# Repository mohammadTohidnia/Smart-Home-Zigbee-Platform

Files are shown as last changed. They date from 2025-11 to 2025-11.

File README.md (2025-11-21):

# Smart-Home-Zigbee-Platform 

**A comprehensive, cost-effective, and scalable solution for residential automation using the Zigbee protocol.**

## Project Overview
This project addresses common challenges in smart home development, such as power consumption, network coverage, and device integration. We have designed a complete system based on the Zigbee protocol that includes custom hardware and software integration.

Key capabilities include:
* **Universal Compatibility:** Capable of adding any Zigbee device from any brand to the network.
* **Automatic Device Discovery:** Seamless integration of new nodes.
* **Real-time Control:** Instant feedback and command execution via a remote platform.
* **Extended Network Coverage:** Robust signal stability using custom router nodes.
* **High Scalability:** Designed to support a large number of devices in a mesh network.

## System Architecture
The platform consists of three main components:

1.  **Zigbee Hub (Central Node)** 
    * **Hardware:** A **custom-designed PCB** hosting an **Orange Pi Zero 3**. It integrates the Zigbee module and power management to act as the network coordinator.
    * **Software:** Runs **Zigbee2MQTT** to bridge Zigbee traffic to the MQTT protocol, transmitting data to **ThingsBoard** for monitoring and control.

2.  **Zigbee Router (Repeater)** 
    * **Function:** Enhances network coverage and signal stability by relaying messages between End Devices and the Hub.
    * **Design:** A standalone custom PCB powered by a 5V adapter.

3.  **In-Wall Switch (End Device)** 
    * **Function:** Smart lighting control with manual override capabilities.
    * **Design:** A compact custom PCB designed to fit into standard wall switch boxes, controlling high-voltage loads via a relay.

---

# 1. Zigbee Hub (Central Node) 

The Hub acts as the brain of the system, hosting the MQTT broker and bridging Zigbee communication to the ThingsBoard platform.

## Hardware
* **Core:** [Orange Pi Zero 3](http://www.orangepi.org/).
* **Carrier Board:** Custom-designed PCB acting as the main hub.
* **Zigbee Module:** **RF-BM-2652P4I** (based on TI CC2652P7), integrated directly onto the custom PCB.

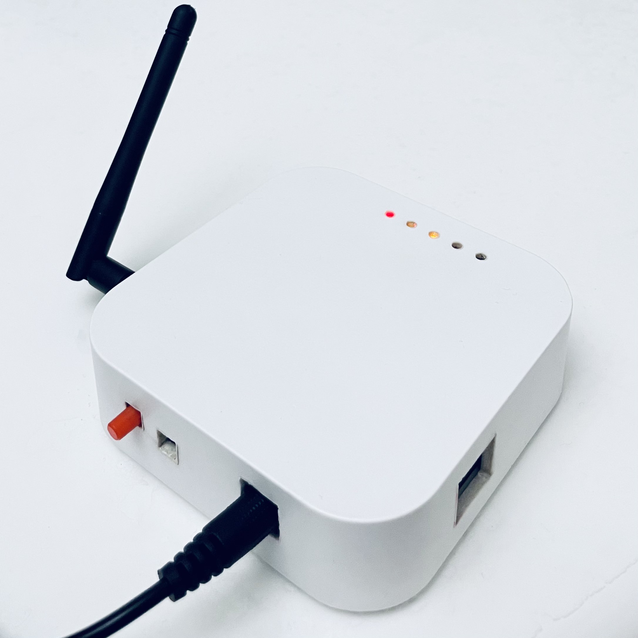
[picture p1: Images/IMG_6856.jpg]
ZigBee Hub


## Software Setup

### 1. Orange Pi Setup (OS & Connectivity)
We used the **Orange Pi Zero 3** as the computational platform.

* **OS Installation:**
    1.  Download the **Debian Bookworm** image from the [Orange Pi Website](http://www.orangepi.org/html/serviceAndSupport/index.html).
    2.  Download and install [Balena Etcher](https://balena.io/etcher).
    3.  Flash the image onto a microSD card (min 8GB).
* **Initial Connection (UART):**
    * Connect a **USB-TTL converter** to the Orange Pi (TX to RX, RX to TX).
    * Open a serial terminal (e.g., [MobaXterm](https://mobaxterm.mobatek.net/)) at **115200 baud** to access the console.
* **Network & SSH:**
    * Connect to Wi-Fi:
        ```bash
        sudo nmtui
        ```
    * Get the IP address:
        ```bash
        ip a
        ```
    * Connect via SSH for easier management:
        ```bash
        ssh orangepi@<YOUR_IP_ADDRESS>
        ```

### 2. Installing Dependencies & Broker
To bridge Zigbee devices with the MQTT protocol, we need Node.js and an MQTT broker.

1.  **Install Basic Tools & Mosquitto Broker:**
    ```bash
    sudo apt update
    sudo apt install -y mosquitto mosquitto-clients git make g++ gcc
    ```
2.  **Install Node.js (Required for Z2M):**
    ```bash
    curl -fsSL [https://deb.nodesource.com/setup_20.x](https://deb.nodesource.com/setup_20.x) | sudo -E bash -
    sudo apt install -y nodejs
    ```
3.  **Verify Installation:**
    ```bash
    node -v
    npm -v
    ```

### 3. Installing Zigbee2MQTT
We followed the official [Linux Installation Guide](https://www.zigbee2mqtt.io/guide/installation/01_linux.html).

1.  **Clone the Repository:**
    ```bash
    sudo git clone [https://github.com/Koenkk/zigbee2mqtt.git](https://github.com/Koenkk/zigbee2mqtt.git) /opt/zigbee2mqtt
    sudo chown -R $USER:$USER /opt/zigbee2mqtt
    ```
2.  **Install Dependencies:**
    ```bash
    cd /opt/zigbee2mqtt
    npm ci
    ```

### 4. Configuration
Edit the configuration file to target the custom PCB's serial port and the local broker.

1.  **Open Configuration:**
    ```bash
    nano /opt/zigbee2mqtt/data/configuration.yaml
    ```
2.  **Paste Configuration:**
    ```yaml
    # MQTT Settings
    mqtt:
      base_topic: zigbee2mqtt
      server: 'mqtt://localhost'

    # Serial Settings (Custom PCB)
    serial:
      port: /dev/ttyS5       # UART5 connected to CC2652P7
      baudrate: 115200
      adapter: zstack

    # Frontend (Web Interface)
    frontend:
      enabled: true
      port: 8080
    ```
3.  **Start Zigbee2MQTT:**
    ```bash
    npm start
    ```

### 5. Flashing the Firmware (CC2652P7)
The **RF-BM-2652P4I** chip on the PCB requires the Z-Stack Coordinator firmware.

* **Firmware:** Use this [link](https://github.com/JelmerT/cc2538-bsl) to access the required firmware based on your hardware.
* **Tool:** [cc2538-bsl](https://github.com/JelmerT/cc2538-bsl).
* **Steps:**
    1.  Hold the **BOOT** button on the PCB and press **RESET** to enter bootloader mode.
    2.  Run the flashing command:
        ```bash
        python3 cc2538-bsl.py -p /dev/ttyS5 -evw coordinator_firmware.hex
        ```

### 6. ThingsBoard Integration (Cloud Bridge) 
To enable remote monitoring and control, we developed a custom Python script that acts as a bridge between the local MQTT broker (Mosquitto) and the ThingsBoard Cloud platform.

#### Features
* **Telemetry Upload:** Pushes `Linkquality` and `LED` status from Zigbee2MQTT to ThingsBoard.
* **Remote Control (RPC):** Listens for `setLED` commands from ThingsBoard to toggle the In-Wall Switch.

#### Setup
1.  **Install Python Dependencies:**
    The script requires the Paho MQTT client.
    ```bash
    sudo apt install python3-pip
    pip3 install paho-mqtt
    ```

2.  **Configuration:**
    Open the python script (`/Software/codes/zig_to_tb/zig_to_tb3.py`) and update the **ThingsBoard settings**:
    ```python
    THINGSBOARD_HOST = 'tb2.thingsware.cloud'
    ACCESS_TOKEN = 'YOUR_ACCESS_TOKEN' # Replace with your actual ThingsBoard Device Token
    ```

3.  **Running the Bridge:**
    You can run the script manually for testing:
    ```bash
    python3 zig_to_tb3.py
    ```

---

# 2. Zigbee Router (Repeater) 

The Zigbee Router is a standalone node designed to extend the range and stability of the network. It operates solely using the Zigbee module and does not require a computational board.

## Hardware
* **Zigbee Module:** **RF-BM-2652P4I** (TI CC2652P7).
    * Selected for its high output power (20 dBm) to maximize range.
* **Power Supply:** 5V 1A adapter with an **AMS1117-3.3** regulator.
* **Antenna:** External antenna via IPEX connector.
* **Enclosure:** Custom casing.

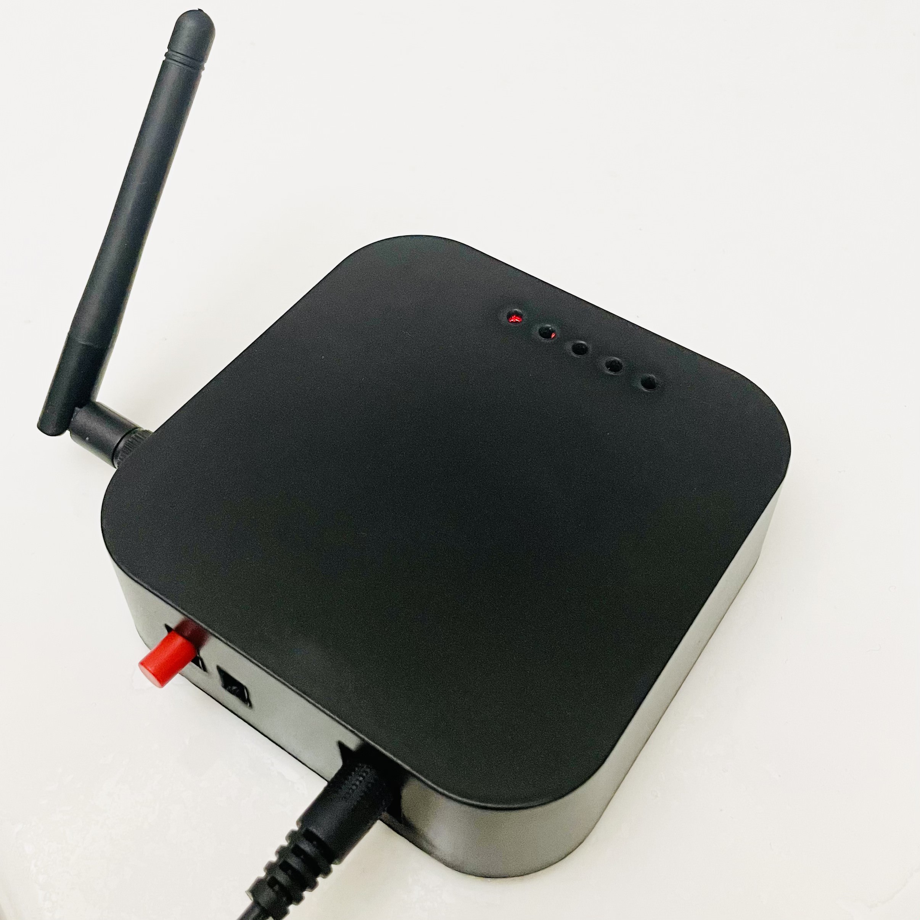
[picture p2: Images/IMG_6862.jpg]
ZigBee Router


## Functionality
* **Signal Repeater:** Relays data between End Devices and the Hub.
* **Mesh Networking:** Healing and routing for network stability.

## Firmware Setup
To configure and flash the router, we use the **PTVO** tool to generate a custom firmware image, followed by `cc2538-bsl` to upload it.

### Step 1: Generate Firmware
1.  Download and install **[Zigbee Configurable Firmware (PTVO)](https://ptvo.info/)**.
2.  Open the tool and select **CC2652P7** as the target chip.
3.  Configure the device role as **Router**.
4.  (Optional) Map any status LEDs or diagnostic pins used on the custom PCB.
5.  Save/Generate the firmware file (e.g., `router_firmware.hex`).

### Step 2: Flash Firmware
1.  **Connect:** Attach the Router PCB to your PC using a **USB-TTL converter**.
2.  **Enter Boot Mode:** Hold the **BOOT** button on the PCB, press **RESET**, then release BOOT.
3.  **Flash:**
    ```bash
    python3 cc2538-bsl.py -p <YOUR_PC_COM_PORT> -evw router_firmware.hex
    ```

---

# 3. Zigbee In-Wall Switch (End Device) 

The In-Wall Switch is a smart end device capable of controlling AC loads (lights/appliances). It supports both wireless control via Zigbee and manual control via a physical button.

## Hardware
* **Chip:** **ESP32-C6** (Supports Zigbee 3.0, Wi-Fi 6, BLE 5.0).
* **Power:** **WX-DC12003** AC-DC converter (Mains to 5V) + **AMS1117-3.3**.
* **Relay:** **HF49FD** (5A, 250V AC) for load switching.
* **Safety:** Includes a slow-blow fuse (0697H1000-02) for overcurrent protection.

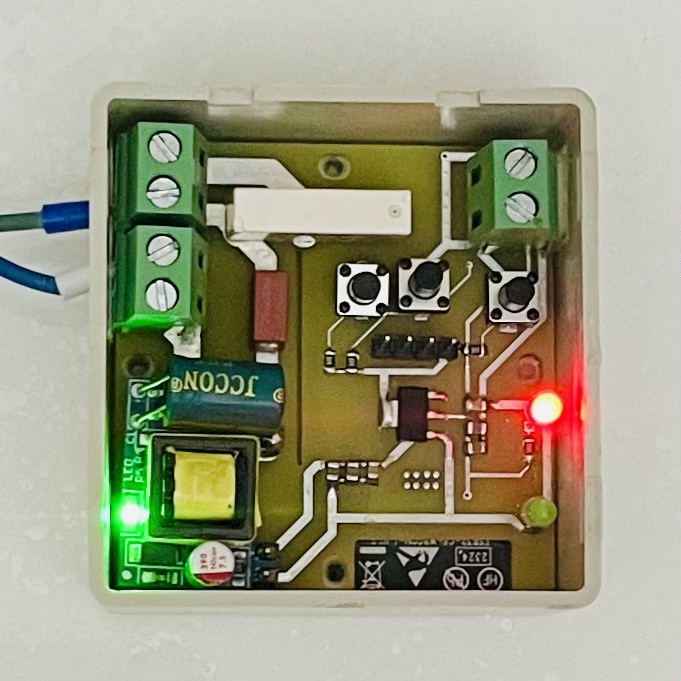
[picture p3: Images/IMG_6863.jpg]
ZigBee In-Wall Switch1

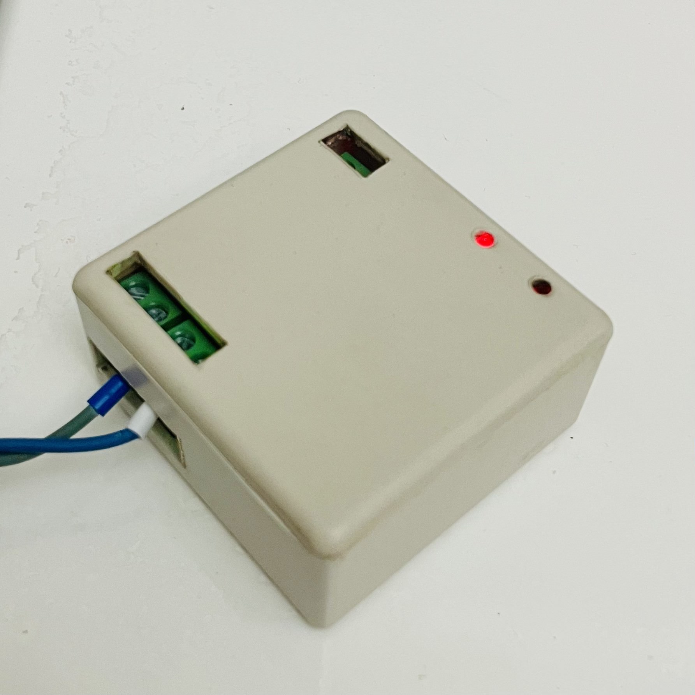
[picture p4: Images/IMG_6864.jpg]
ZigBee In-Wall Switch2


## Firmware Logic (C++)
The firmware was developed using the **Arduino IDE** and the **ESP32 Zigbee SDK**. The source code is located in the `/In-Wall-Switch/Firmware` directory.

### Key Features:
1.  **Zigbee End Device:** Acts as an endpoint in the network.
2.  **Pairing Mode:** Holding the physical button for **>5 seconds** triggers factory reset and enters pairing mode (LED flashes fast).
3.  **Manual Override:** Pressing the button toggles the relay and immediately reports the new state to the Hub.
4.  **Connectivity Reporting:** Sends signal strength (`linkquality`) and state (`ON/OFF`) to the Hub.

### Flashing Instructions:
You can flash the firmware using the **Arduino IDE** or the command line tools.

1.  **Connect:** Attach the Switch PCB to your PC via USB-TTL (connected to the ESP32-C6 UART pins).
2.  **Enter Boot Mode:** Put the ESP32-C6 into bootloader mode (Hold BOOT, press RESET).
3.  **Flash via Arduino IDE:**
    * Select Board: `ESP32C6 Dev Module`.
    * Select Port: Your COM port.
    * Click **Upload**.
4.  **Flash via Command Line (esptool):**
    ```bash
    esptool.py --chip esp32c6 --port <YOUR_PORT> --baud 115200 write_flash 0x0 switch_firmware.bin
    ```

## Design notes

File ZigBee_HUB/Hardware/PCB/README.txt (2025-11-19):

This is the final version of Zigbee HUB with Orange PI. The features:
1. It is designed in a way that can be used as HUB or Router. If you use HUB, Do not assemble Regulator components. 
If you want Router, you have to assemble the AMS1117 regulator.

2. It has some pin headers for future developments (I2C and SPI of CC2652P4I)

3. It needs a 5V/2A or 5V/3A adaptor to power the board.

4. If you see a voltage drop, you can short circuit the schottky diode.

5. In new version, the LEDs are smd and they need a LENZ to make the light better and straight.

6. If you hold the reset button for more than 3 secs, you put the hub into pairing mode and it allows devices to join the network.

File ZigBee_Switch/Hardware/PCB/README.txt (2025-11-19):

The final version is a zigbee InWall switch with one relay that connects to the Zigbee HUB. The proble is the dimensions of the PCB. 
We have to design a new PCB with other Power Supply that can convert 220 VAC to 5V DC in a small space. My solution is to use LNK306
switching regulator that offers a good output current for this circuit. The schematic is in this LInK : https://www.instructables.com/LNK304-Transformerless-Power-Supply/
The goal is to design a PCb less than 50 mm in dimensions.

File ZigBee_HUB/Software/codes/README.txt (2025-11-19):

File "Connection Status" -> A python code for GPIO pins of Orange pi to control the led indicators for connection status.
This file is the final version and the code works fine.

File "Zig_to_tb" -> A python code to connect the zigbee network to thingsboard. You need the Access token of your device in this code.
The code works fine, but it is needed to get better. For example, we have to write a code that creates the hub as a device in thingsboard
automatically. In this way, there is no need to define access token for each device. For now, "zig_to_tb3" is better version that can
connect to thingsboard.

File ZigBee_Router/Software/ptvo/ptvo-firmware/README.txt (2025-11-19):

This firmware allows you to create a device with a flexible configuration of inputs and outputs.

The device with this firmware also works as a router.

How to use
=========================

1. Launch the "FirmwareConfig.exe" utility.
2. Configure the firmware for your chip, board, and needs. Optionally, you may click the "File - Read settings from a file" menu item and load settings from an existing preset in the "Presets" folder.
3. Click the "Save" button and get the final HEX file. Note: some features may require the Premium version of this firmware.

Options
=========================

Remember state - The firmware saves the output state to NVRAM and restores it after power off/on.

Link - The input immediately controls the state of the corresponding output. The device sends the on/off state of
the output to a coordinator. Otherwise, the input is independent.

Long - The firmware detects and reports to the coordinator a long click (2000 ms)

Double - The firmware detects and reports double click (max 500 ms between clicks)

Tripple - The firmware detects and reports tripple click (max 500 ms between clicks)

Switch - an input works as a switch. Only ON (pushed) / OFF (released) states.

UART
=========================

The UART interface is designed to send text commands between an external device (e.g. Arduino) and a host. 

The maximum command size is 127 characters. Every command line should ends with CR (0x0D). If you need 
to send a number to a host, you should convert it to text.

UART uses P02 and P03 pins (3.3V). You should enable UART on one of output pins in the configuration.

UART parameters: 9600 8N1. You cannot change these parameters.

External sensors 
=========================

The firmware supports up to 8 external sensors of different types. 
Keep in mind, that CC253x has limited performance. You cannot attach 8 sensors, 4 inputs, UART and get a good result.
Some sensors cannot co-exist with each other.

I2C sensors (BMx280, SI7021, etc)
---
You should define a pin for a sensor first. It is the SDA pin. Then you should define the SCL pin. 
For example, output 7 - BME280, and output 8 - I2C SCL

DS18B20
---
The firmware supports up to 4 sensors on one line. But all values will be sent to one endpoint with a different description.

Pulse generator
---
You may use this generator to wake-up Atmega based sensor. That should measure a value and output it to an UART port.

Pulse counter
---
It is 32 bit counter with the 10 milliseconds debounce interval. Therefore it cannot be used for high frequence signals.
If an interval is defined, the counter automatically resets after that interval and reports the counted values to a coordinator.

MHZ19, Senseair
---
These sensors should work in the UART mode and connected to UART pins. Therefore you cannot use the UART interface in the same
configuration. (CC2530 P0.2 -> MH-Z19 RX, CC2530 P0.3 -> MH-Z19 TX)

Bistable relay
==========================

You should define ON pin first. For example, output 7 - Bistable relay ON, and output 8 - Bistable relay OFF

Analog inputs
==========================

You may define up to 8 analog inputs in the configuration. You can connect analog inputs to pins P00..P07.

Analog input, accurate (max 1.15V) - the pin uses internal reference voltage that is more precise than an source voltage.
Analog input, (max 3.3V) - less accurate, but it can measure higher voltage.
Source voltage - reports source power voltage. It can be used to monitor a battery level.
Internal temperature - reports a temperature of the CC2530 chips.

The firmware reads analog values when it sends a periodic report to a host. When the periodic report is disabled you should
send the "read" request for the configured endpoint.

Experts options
==========================

You should know what you change.

Zigbee internals
=========================

1. The firmware creates a separate endpoint (1..8) for every configured output and/or input (max 8 endpoints).

2. The firmware reports the state of an independent button via the "ZCL_CLUSTER_ID_GEN_MULTISTATE_INPUT_BASIC" cluster 
   and the "PRESENT_VALUE" attribute.

   1 - single click.
   2 - double click.
   3 - tripple click.
   4 - long click.

4. The firmware does not send a separate report for the linked button. Otherwise, it sends reports about the output state 
  via the "ZCL_CLUSTER_ID_GEN_ON_OFF" cluster and the "ON_OFF" attribute.
  
5. You may control the output state via the "ZCL_CLUSTER_ID_GEN_ON_OFF" cluster and the "ON_OFF" attribute.

  In zigbee2mqtt you may write ON or OFF to:
  
  Output 1: zigbee2mqtt/[FRIENDLY_NAME]/l1/set
  Output 2: zigbee2mqtt/[FRIENDLY_NAME]/l2/set
  Output 3: zigbee2mqtt/[FRIENDLY_NAME]/l3/set
  Output 4: zigbee2mqtt/[FRIENDLY_NAME]/l4/set
  Output 5: zigbee2mqtt/[FRIENDLY_NAME]/l5/set
  
  or read data using the MQTT topic like:
  
  zigbee2mqtt/[FRIENDLY_NAME]/l1/get
  
  also you may use l1 ... l8 for the corresponding channel.

6. The "ZCL_CLUSTER_ID_GEN_ON_OFF" cluster also accepts the "read", "configure" and "onOffWithTimedOff" commands:

  "read" - returns the current state on the specified endpoint.
  "configure" - set the periodic reporting interval for the output. The "minReportInt" attribute specifies the reporting interval
   in seconds. If "minReportInt" is 65535, the firmware disables periodic reports.     
  "onOffWithTimedOff" - sets the output state to "HIGH" for "onTime" milliseconds, and automatically resets to "LOW".

7. The "ZCL_CLUSTER_ID_GEN_MULTISTATE_VALUE_BASIC" cluster is used to send and receive UART data.
  The cluster accepts the "write" command with the "stateText" attribute. The firmware outputs the content of the attribute 
  to UART and appends CR (0xOD). If the firmware receives a command from UART, it sends data to a host immediately.
  
  In zigbee2mqtt, you may send text data to UART data through MQTT topic:
  
  zigbee2mqtt/[FRIENDLY_NAME]/set/action
  
  or send hex data in the JSON format {"action": [4,3,2,1,0]} to 

  zigbee2mqtt/[FRIENDLY_NAME]/set
  
  Zigbee2MQTT publishes data from UART to the topic zigbee2mqtt/[FRIENDLY_NAME] in the JSON format.

  {..... "action": "your_data" ....} 
  
  If you do not receive data from UART, you should check that data contains CR (0x0D) at the end of a data packet.

8. The "ZCL_CLUSTER_ID_GEN_ANALOG_INPUT_BASIC" cluster accepts the "read" command. The firmware immediately reads an ADC value and returns 
to a host.

  In zigbee2mqtt you may read data through MQTT:
  
  zigbee2mqtt/[FRIENDLY_NAME]/get/l1
  ...
  zigbee2mqtt/[FRIENDLY_NAME]/get/l8

  or
  zigbee2mqtt/[FRIENDLY_NAME]/l1/get/l1
  
9. PWM

ZCL_CLUSTER_ID_GEN_LEVEL_CONTROL

MQTT topic: zigbee2mqtt/[FRIENDLY_NAME]/l4/set
MQTT payload: {"brightness": 1, "transition": 3}

MQTT topic: zigbee2mqtt/[FRIENDLY_NAME]/l4/set/brightness
MQTT payload: brightness value (0-254)

MQTT topic: zigbee2mqtt/[FRIENDLY_NAME]/l4/get/brightness
MQTT payload: none

cc2530-cc2590.hex
=========================
The firmware is compiled for a particular version of the CC2530 board with the additional CC2590/RFX2401 RF chip.

cc2530-cc2591-xxxxx.hex
=========================
The firmware is compiled for a particular version of the CC2530 board with the additional CC2591 RF chip.
Note: The CC2591 RF chip is connected to CC2530 through P11 (PAEN), P14 (EN) and P07 (HGM) pins.
This is the generally used layout.

cc2530-cc2591-hexin-dl22-xxxxx.hex
=========================
The firmware is compiled for a particular version of the CC2530 board with the additional CC2591 RF chip.
Note: The CC2591 RF chip is connected to CC2530 through P14 (PAEN), P15 (EN) and P07 (HGM) pins. This is the proprietary layout!
Links: 
http://www.hexin-technology.com/1000m_TTL_to_ZigBee_Module-Product-566.html
https://ru.aliexpress.com/item/2-4G-Zigbee-Wireless-Transceiver-Module-Long-Distance-Wireless-Serial-Transceiver-Module/32703502764.html

cc2530-cc2592-xxxxx.hex
=========================
The firmware is compiled for a particular version of the CC2530 board with the additional CC2592 RF chip.

Lights
=========================

If the LED pin is configured.

Short fast blinks (one per second) – the router is connecting to a network.
Short long blinks (one per 4 seconds) – normal operations.
Three short blinks – the router cannot send a report to a coordinator.

Pairing
=========================
Flash firmware and permit joining to a network on your coordinator.

Re-pairing
=========================
Power on, wait 2 seconds, power off, repeat this cycle three times.

If you configured first input pin, click and hold it for 10 seconds.

-------------------
More info: https://ptvo.info/zigbee-configurable-firmware-features/
Download: https://ptvo.info/zigbee-switch-configurable-firmware-v2-210/
Home page: https://ptvo.info

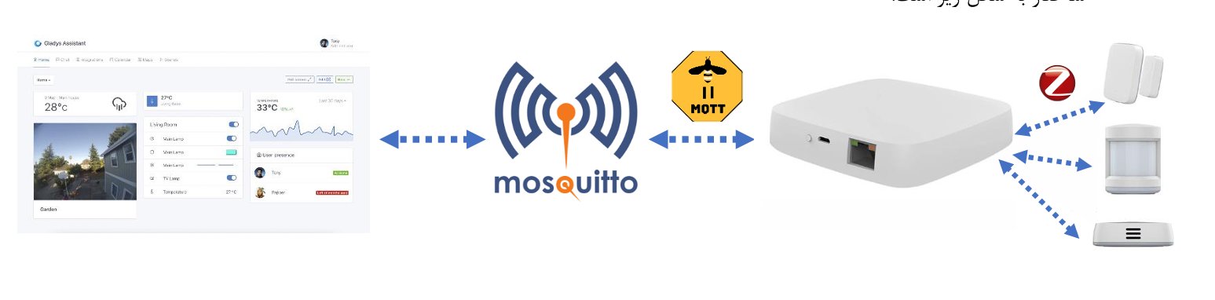
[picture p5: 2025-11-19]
Images/Z2M_Architecture.png

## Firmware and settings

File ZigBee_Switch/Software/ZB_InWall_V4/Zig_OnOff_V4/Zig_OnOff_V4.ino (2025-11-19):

#ifndef ZIGBEE_MODE_ED
#error "Zigbee end device mode is not selected in Tools->Zigbee mode"
#endif

#include "Zigbee.h"

/* Zigbee light bulb configuration */
#define ZIGBEE_LIGHT_ENDPOINT 10
uint8_t Relay_Signal = 23;
uint8_t button = BOOT_PIN;
uint8_t switchOnOff = 20;
uint8_t pairingButton = 21;
uint8_t indicatorLED = 22;

bool last_switch_state= false ;
bool pairingDone = false;

ZigbeeLight zbLight = ZigbeeLight(ZIGBEE_LIGHT_ENDPOINT);

// LED indicator mode enum
enum LedMode {
  LED_OFF,
  LED_ON,
  LED_BLINK_SLOW,
  LED_BLINK_FAST
};

LedMode currentLedMode = LED_BLINK_SLOW;



/********************* Relay_Signal functions **************************/
void setRelay(bool value) {
  digitalWrite(Relay_Signal, value);
  Serial.print("Zigbee command received: ");
  Serial.println(value ? "ON" : "OFF");
}


// Blink logic for status LED
void updateLedBlink() {
  static unsigned long lastBlink = 0;
  static bool ledState = false;
  unsigned long now = millis();

  int interval = 1000;
  if (currentLedMode == LED_BLINK_FAST) interval = 200;
  else if (currentLedMode == LED_BLINK_SLOW) interval = 1000;

  switch (currentLedMode) {
    case LED_ON:
      digitalWrite(indicatorLED, HIGH);
      break;
    case LED_OFF:
      digitalWrite(indicatorLED, LOW);
      break;
    case LED_BLINK_SLOW:
      if (now - lastBlink >= interval) {
          ledState = !ledState;
          digitalWrite(indicatorLED, ledState);
          lastBlink = now;
        }
        break;
    case LED_BLINK_FAST:
      if (now - lastBlink >= interval) {
        ledState = !ledState;
        digitalWrite(indicatorLED, ledState);
        lastBlink = now;
      }
      break;
  }
}




/********************* Arduino functions **************************/
void setup() {
  Serial.begin(115200);

  // Init Relay_Signal and turn it OFF (if Relay_Signal_PIN == RGB_BUILTIN, the rgbRelay_SignalWrite() will be used under the hood)
  pinMode(Relay_Signal, OUTPUT);
  digitalWrite(Relay_Signal, LOW);

  // Initialize modes 
  pinMode(button, INPUT);
  pinMode(switchOnOff, INPUT);
  pinMode(pairingButton, INPUT);
  pinMode(indicatorLED, OUTPUT);
  digitalWrite(indicatorLED, LOW);


  //Optional: set Zigbee device name and model
  zbLight.setManufacturerAndModel("Espressif", "ZBInWall");

  // Set callback function for light change
  zbLight.onLightChange(setRelay);

  //Add endpoint to Zigbee Core
  Serial.println("Adding ZigbeeLight endpoint to Zigbee Core");
  Zigbee.addEndpoint(&zbLight);

  // When all EPs are registered, start Zigbee. By default acts as ZIGBEE_END_DEVICE
  if (!Zigbee.begin()) {
    Serial.println("Zigbee failed to start!");
    currentLedMode = LED_OFF ;
    updateLedBlink() ;
    Serial.println("Rebooting...");
    ESP.restart();
  }

  Serial.println("Connecting to network");
  while (!Zigbee.connected()) {
    Serial.print(".");
    delay(100);
    updateLedBlink() ;
  }
  Serial.println();
  //currentLedMode = LED_ON;
}

void loop() {
  // Checking button for factory reset
  if (digitalRead(button) == LOW) {  // Push button pressed
    // Key debounce handling
    delay(100);
    int startTime = millis();
    while (digitalRead(button) == LOW) {
      delay(50);
      if ((millis() - startTime) > 3000) {
        // If key pressed for more than 3secs, factory reset Zigbee and reboot
        Serial.println("Resetting Zigbee to factory and rebooting in 1s.");
        delay(1000);
        Zigbee.factoryReset();
      }
    }
  }

  /* Pairing button logic
  if ((!pairingDone) && (digitalRead(pairingButton) == LOW)) {
    delay(100);
    unsigned long pressStart = millis();
    while (digitalRead(pairingButton) == LOW) {
      if (millis() - pressStart > 3000) {
        Serial.println("Entering pairing mode...");
        currentLedMode = LED_BLINK_FAST;
        pairingDone = true;
        Zigbee.factoryReset();
        break;
      }
      delay(50);
    }
  }*/


  // Switch state logic
  bool current_switch_state = (digitalRead(switchOnOff) == HIGH);
  if (current_switch_state != last_switch_state) {
    last_switch_state = current_switch_state;
    zbLight.setLight(current_switch_state);
    zbLight.setLight(zbLight.getLightState());
  }

  // If connected to Zigbee, set LED ON
  if (Zigbee.connected()) {
    currentLedMode = LED_ON;
  }
  else{
    currentLedMode = LED_BLINK_SLOW ;
  }


  updateLedBlink() ;
  delay(100);
}

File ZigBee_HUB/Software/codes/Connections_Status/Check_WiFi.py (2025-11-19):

import OPi.GPIO as gpio
import time
import subprocess
import threading
import paho.mqtt.client as mqtt
import json

# Define GPIO pins
WIFI_LED = 'PC9'
MQTT_LED = 'PC6'
PAIR_LED = 'PC5'
PAIR_BUTTON = 'PC1'

# Setup GPIO
gpio.setmode(gpio.SUNXI)
gpio.setup(WIFI_LED, gpio.OUT)
gpio.setup(MQTT_LED, gpio.OUT)
gpio.setup(PAIR_LED, gpio.OUT)
gpio.setup(PAIR_BUTTON, gpio.IN, pull_up_down=gpio.PUD_UP)

# Global flags
mqtt_connected = False
z2m_online = False
pairing_mode = False

# Functions
def is_wifi_connected():
    try:
        result = subprocess.check_output(["nmcli", "-t", "-f", "DEVICE,STATE", "dev"], universal_newlines=True)
        for line in result.splitlines():
            if line.startswith("wlan0:"):
                state = line.split(":")[1]
                return state == "connected"
    except Exception as e:
        print(f"Error checking Wi-Fi status: {e}")
    return False

def LED_Blink(led_pin, blink_time):
    gpio.output(led_pin, 1)
    time.sleep(blink_time)
    gpio.output(led_pin, 0)
    time.sleep(blink_time)

def wifi_led_thread():
    Delay_Time = 3
    while True:
        if is_wifi_connected():
            gpio.output(WIFI_LED, 1)
            print("Connected to Wi-Fi")
            time.sleep(Delay_Time)
        else:
            print("Wi-Fi disconnected, blinking...")
            for _ in range(int(Delay_Time / 0.6)):
                LED_Blink(WIFI_LED, 0.3)

def mqtt_led_thread():
    Delay_Time = 3
    while True:
        if mqtt_connected and z2m_online:
            gpio.output(MQTT_LED, 1)
            print("Zigbee2MQTT is online")
            time.sleep(Delay_Time)
        else:
            print("Zigbee2MQTT is offline or MQTT disconnected, blinking...")
            for _ in range(int(Delay_Time / 0.6)):
                LED_Blink(MQTT_LED, 0.3)

def permit_join_thread():
    global pairing_mode
    while True:
        if gpio.input(PAIR_BUTTON) == 0:  # Button pressed
            start_time = time.time()
            while gpio.input(PAIR_BUTTON) == 0:
                time.sleep(0.1)
                if time.time() - start_time >= 3:
                    print("Button held for 3 seconds. Enabling pairing mode...")
                    pairing_mode = True
                    client.publish("zigbee2mqtt/bridge/request/permit_join", json.dumps({"value": True, "time": 120}))
                    
                    # Blink fast for 5 seconds
                    start_blink = time.time()
                    while time.time() - start_blink < 5:
                        LED_Blink(PAIR_LED, 0.1)
                    
                    gpio.output(PAIR_LED, 0)  # Ensure LED off
                    pairing_mode = False
                    break
        time.sleep(0.1)

def device_message_blink_thread():
    while True:
        if device_message_event.wait():
            if not pairing_mode:
                LED_Blink(PAIR_LED, 0.1)
            device_message_event.clear()

# MQTT Callbacks
def on_connect(client, userdata, flags, rc):
    global mqtt_connected
    mqtt_connected = (rc == 0)
    if mqtt_connected:
        print("MQTT Connected")
        client.subscribe("zigbee2mqtt/bridge/state")
        client.subscribe("zigbee2mqtt/#")
    else:
        print(f"MQTT Failed with code {rc}")

def on_disconnect(client, userdata, rc):
    global mqtt_connected
    mqtt_connected = False
    print("MQTT Disconnected")

def on_message(client, userdata, msg):
    global z2m_online

    if msg.topic == "zigbee2mqtt/bridge/state":
        payload = msg.payload.decode()
        print(payload)
        if "online" in payload:
            z2m_online = True
        else:
            z2m_online = False
        print(f"Zigbee2MQTT state: {payload}")
    
    elif msg.topic.startswith("zigbee2mqtt/") and not msg.topic.startswith("zigbee2mqtt/bridge/"):
        print(f"Device message: {msg.topic}")
        device_message_event.set()

# Setup MQTT
client = mqtt.Client()
client.on_connect = on_connect
client.on_disconnect = on_disconnect
client.on_message = on_message

client.connect_async("localhost", 1883, 60)
client.loop_start()

# Events
device_message_event = threading.Event()

# Start threads
threads = [
    threading.Thread(target=wifi_led_thread, daemon=True),
    threading.Thread(target=mqtt_led_thread, daemon=True),
    threading.Thread(target=permit_join_thread, daemon=True),
    threading.Thread(target=device_message_blink_thread, daemon=True)
]

for t in threads:
    t.start()

# Keep main thread alive
try:
    gpio.output(MQTT_LED, 0)
    gpio.output(PAIR_LED, 0)
    while True:
        time.sleep(1)
        print("Button state:", gpio.input(PAIR_BUTTON))
except KeyboardInterrupt:
    gpio.cleanup()
    client.loop_stop()
    client.disconnect()
